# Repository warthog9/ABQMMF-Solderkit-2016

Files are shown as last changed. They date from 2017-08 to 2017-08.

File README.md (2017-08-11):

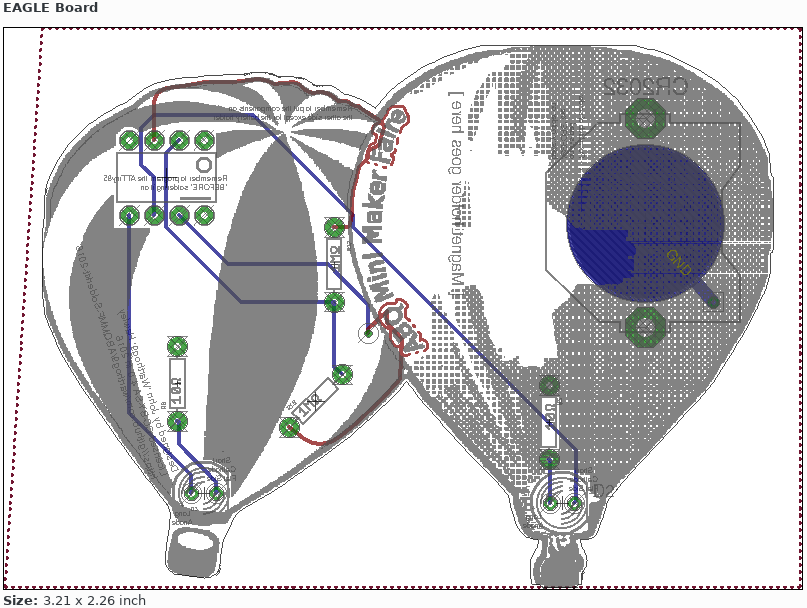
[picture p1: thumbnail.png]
Thumbnail of balloon soldering kit

This is the learn to solder badge for the Albuquerque Mini Maker Faire.

License:
	The design is opened based on the Creative Commons CC-BY-SA 4.0
	[https://creativecommons.org/licenses/by-sa/4.0/](https://creativecommons.org/licenses/by-sa/4.0/)

	Copyright on the badge is held by John 'Warthog9' Hawley

	The badges themselves use a silkscreen that has elements that
	have been removed from this repository, they are not required
	for the functionality, and were removed out of respect for the
	various originators of the symbols.

	Rough outline of the balloons was adapted from
	[https://pixabay.com/en/hot-air-balloon-balloon-striped-312574/](https://pixabay.com/en/hot-air-balloon-balloon-striped-312574/)
	which was listed as released into Public Domain when acquired on
	May 27, 2016

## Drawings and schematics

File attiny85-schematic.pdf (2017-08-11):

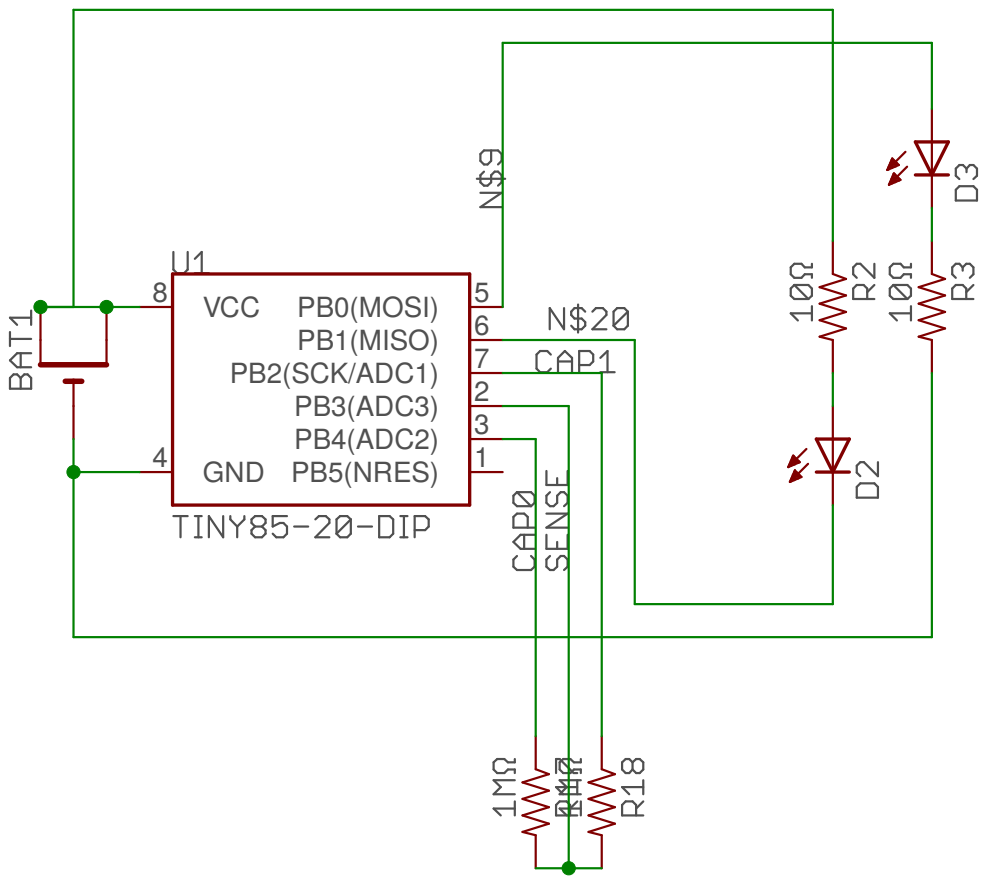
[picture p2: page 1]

8/10/17 7:42 PM /home/warthog9/eagle/ABQ Maker Faire Soldering Kit/attiny85.sch (Sheet: 1/1)

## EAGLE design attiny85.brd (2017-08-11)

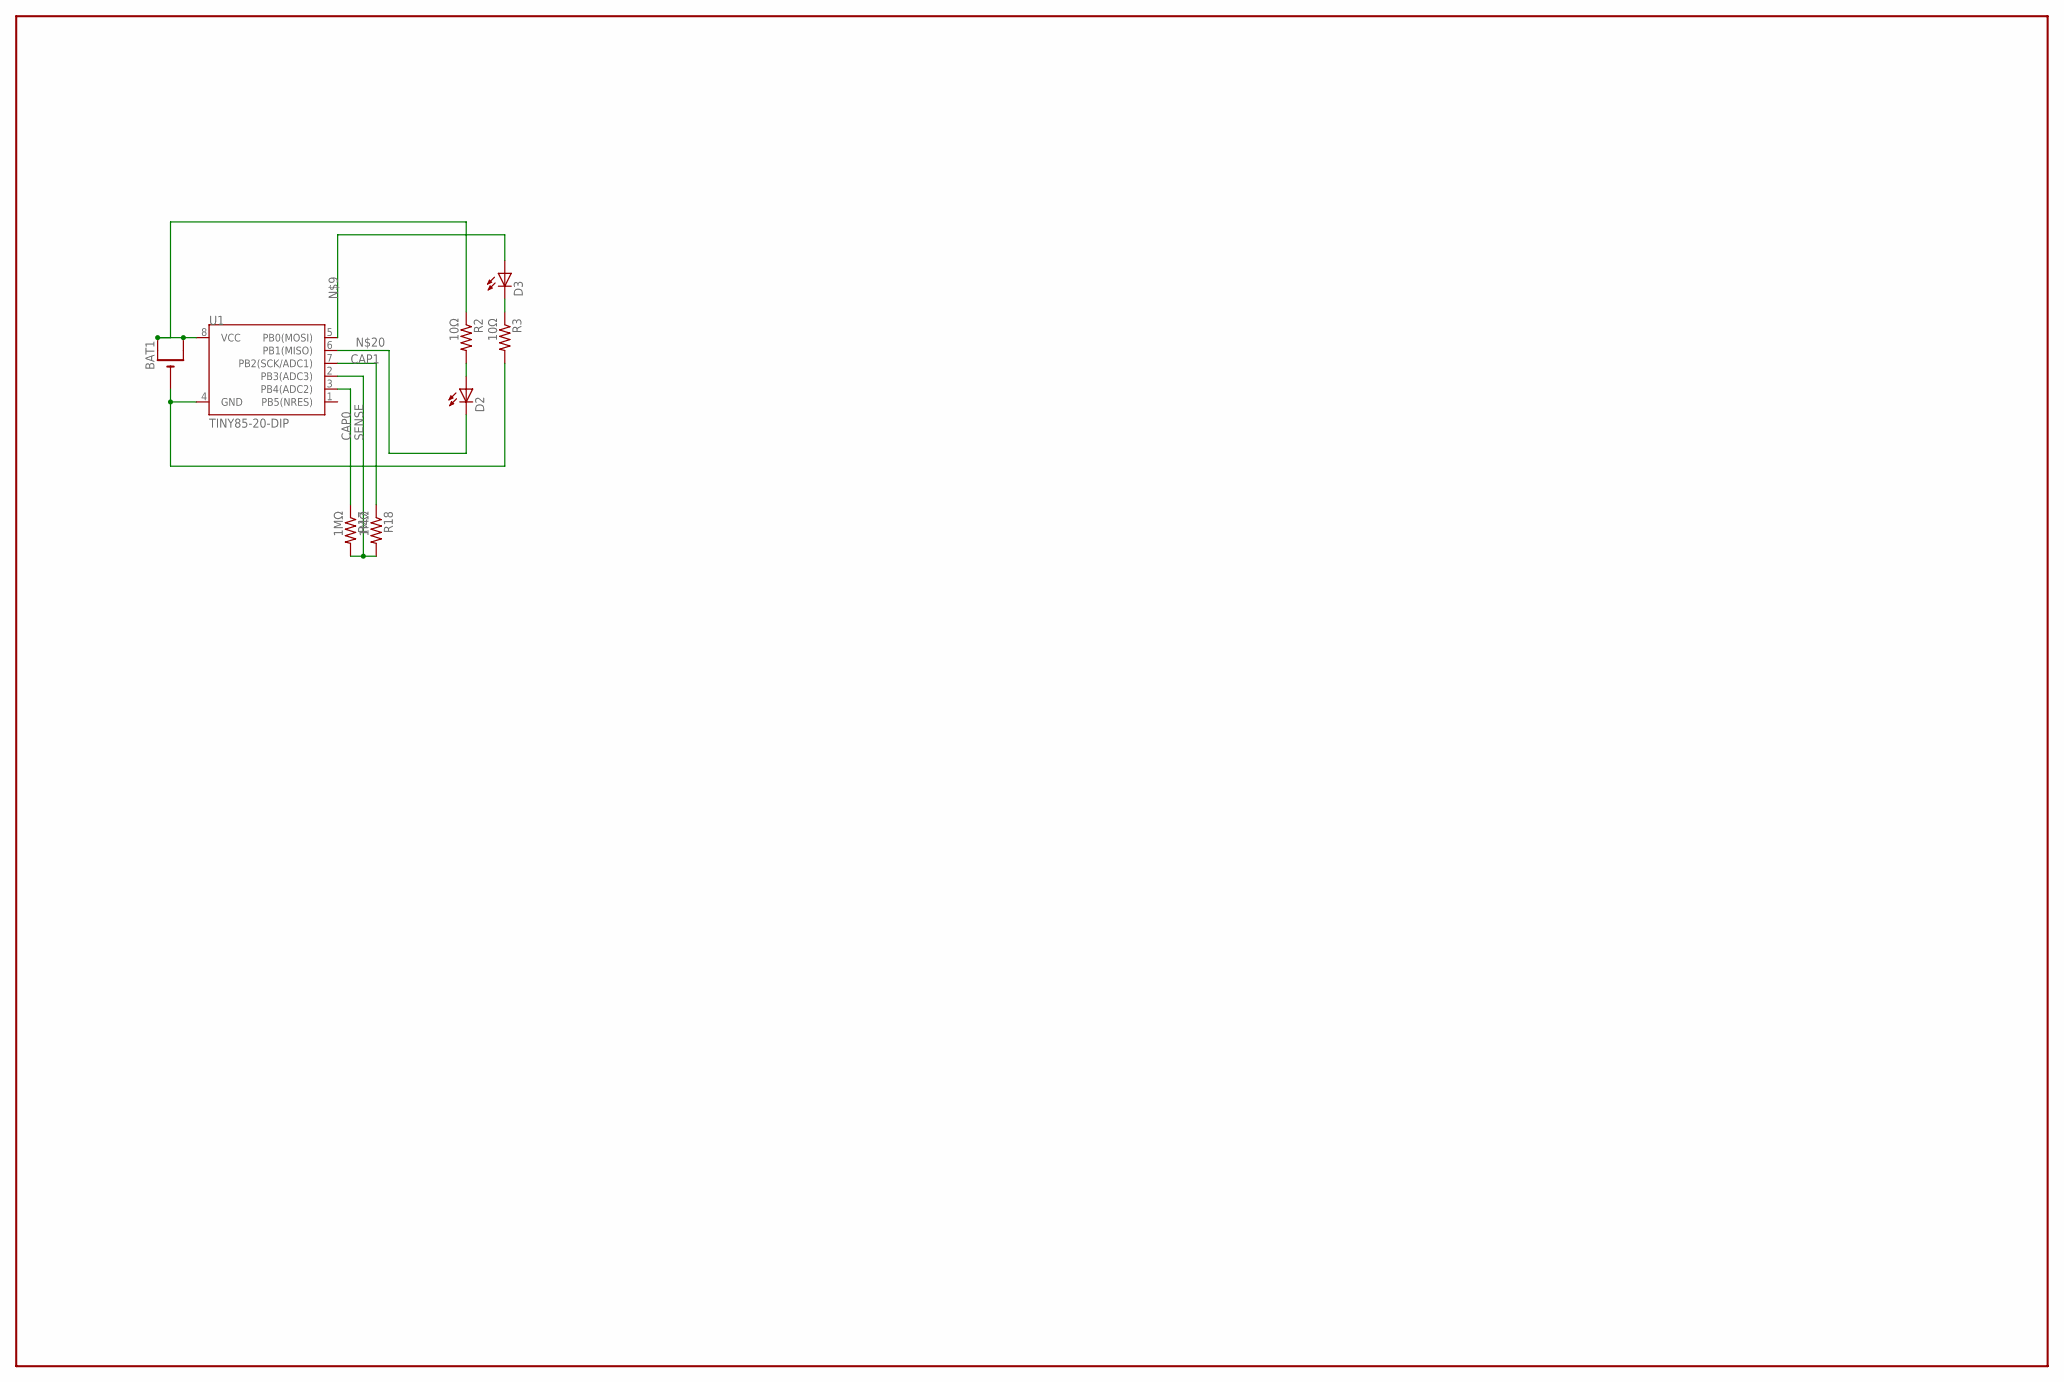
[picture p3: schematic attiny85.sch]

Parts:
BAT1: CR2032THM; CR2032-THRU
D2, D3: LED5MM
R2, R3: 10Ω; AXIAL-0.3
R17, R18: 1MΩ; AXIAL-0.3
U1: TINY85-20-DIP; DIP08

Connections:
CAP0: R17.P$1 (1), U1.3 (PB4(ADC2))
CAP1: R18.P$1 (1), U1.7 (PB2(SCK/ADC1))
GND: BAT1.-, R3.P$2 (2), U1.4 (GND)
unnamed: D2.A, R2.P$2 (2)
unnamed: D3.K (C), R3.P$1 (1)
unnamed: D3.A, U1.5 (PB0(MOSI))
unnamed: D2.K (C), U1.6 (PB1(MISO))
SENSE: R17.P$2 (2), R18.P$2 (2), U1.2 (PB3(ADC3))
VCC: BAT1.+1 (+), BAT1.+2 (+1), R2.P$1 (1), U1.8 (VCC)

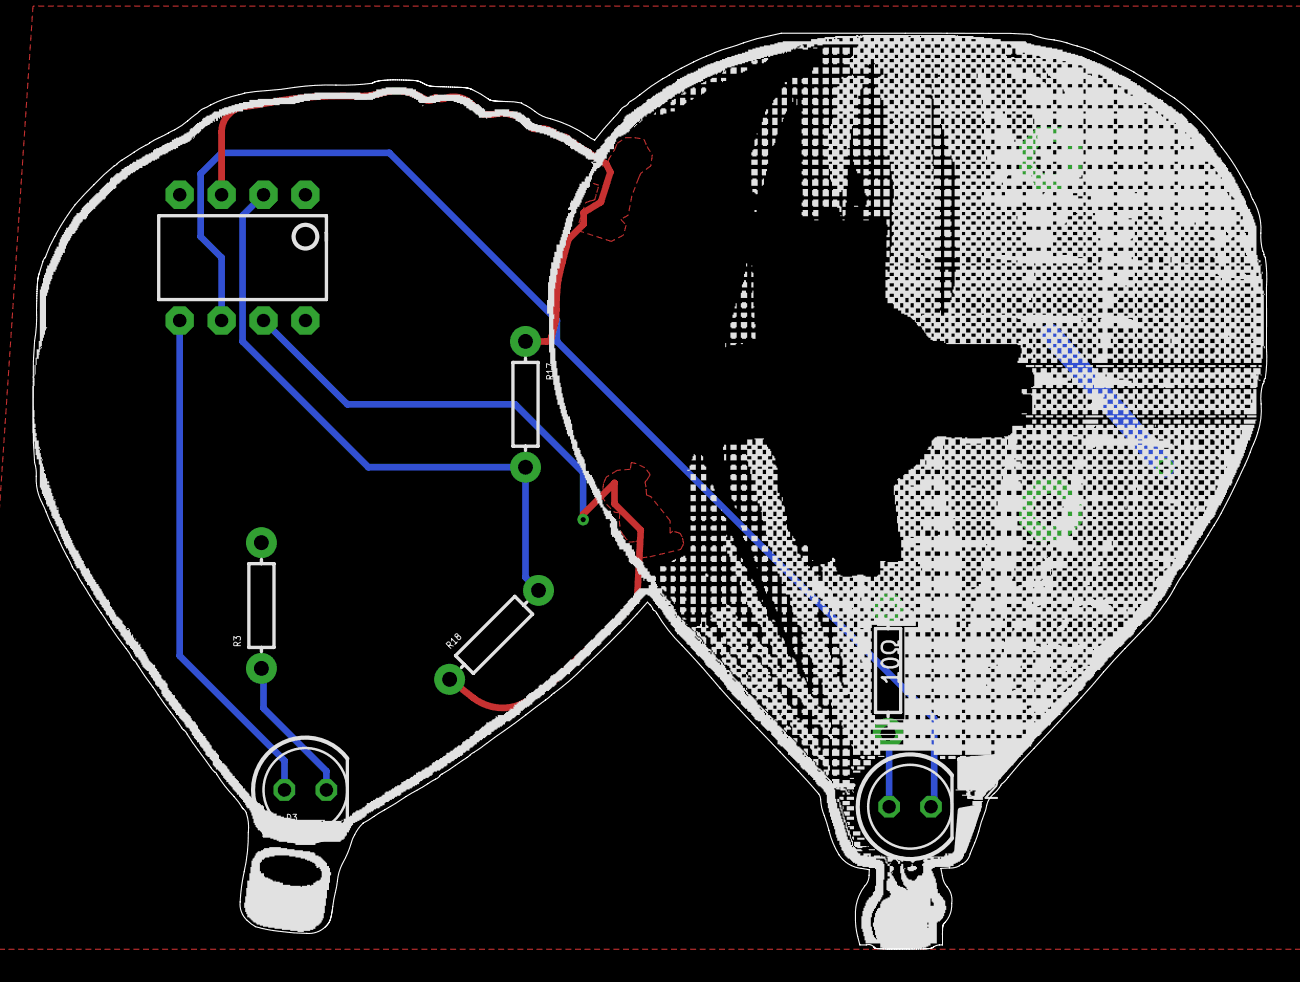
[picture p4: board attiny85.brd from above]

Board: 2 copper layers, 74.7 x 55.5 mm, 8 parts (1 on the bottom side), 9 nets.

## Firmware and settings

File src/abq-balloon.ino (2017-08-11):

int leftBaloonLEDPin = 0;
int rightBaloonLEDPin = 1;

int abqTouchPin = 2;
int faireTouchPin = 4;

int maxBrightness = 128;

void setup()
{
  pinMode(leftBaloonLEDPin, OUTPUT);
  pinMode(rightBaloonLEDPin, OUTPUT);
  
  digitalWrite(leftBaloonLEDPin, HIGH);   // sets the LED on
  delay(1000);                  // waits for a second
  digitalWrite(leftBaloonLEDPin, LOW);    // sets the LED off
  delay(1000);                  // waits for a second
  
  digitalWrite(rightBaloonLEDPin, LOW);   // sets the LED on
  delay(1000);                  // waits for a second
  digitalWrite(rightBaloonLEDPin, HIGH);    // sets the LED off
  delay(1000);                  // waits for a second
  
  // Left pin low is off
  digitalWrite(leftBaloonLEDPin, LOW);
  // right pin, high should be off
  digitalWrite(rightBaloonLEDPin, HIGH);
}

void loop()
{
  int state = random(0,2);
  
  if( state == 0 || state == 1){
    
    // Run one LED
    
    int whichLED = 0;
    
    if( state == 0 ){
       // Run the left LED
       whichLED = leftBaloonLEDPin;
    } else if( state == 1 ){
      // Run the right LED
      whichLED = rightBaloonLEDPin;
    }

    // fade the LED on thisPin from off to brightest:
    for (int brightness = 0; brightness < maxBrightness; brightness++) {
      int useBright = brightness;
      if( state == 1 ){
        // right led
        useBright = 255 - brightness;
      }
      analogWrite(whichLED, useBright);
      delay(5);
    }
  
    // Flicker at the "top" of the brightness, like a balloon
    int totalHighTime = random(250,1500);
  
    for (int highTime = 0; highTime <= totalHighTime; highTime = highTime + 5) {
      int randBright = random(maxBrightness - 50,maxBrightness);
      int useBright = randBright;
      
      if( state == 1 ){
        // right led
        useBright = 255 - randBright;
      }
      
      analogWrite(whichLED, useBright);
      delay(5);
    }
    // end "top" flicker
  
    // fade the LED on thisPin from brithstest to off:
    for (int brightness = maxBrightness; brightness >= 0; brightness--) {
      int useBright = brightness;
      
      if( state == 1 ){
        // right led
        useBright = 255 - brightness;
      }
      
      analogWrite(whichLED, useBright);
      delay(2);
    }
  
    int totalLowTime = random(250,1500);
  
    for (int lowTime = 0; lowTime <= totalLowTime; lowTime = lowTime + 5) {
      int useBright = random(0,12);
      
      if( state == 1 ){
        // right led
        useBright = 255 - useBright;
      }
      analogWrite(whichLED, useBright);
      delay(5);
    }
    
    if( state == 0 ){
      analogWrite(whichLED, 0);
    } else if( state == 1 ){
      analogWrite(whichLED, 255);
    }
  
    // Pulse
    if( random() % 2 == 0 ){
      for (int brightness = 0; brightness < maxBrightness; brightness++) {
         int useBright = brightness;
      
         if( state == 1 ){
           // right led
           useBright = 255 - brightness;
         }        
         
         analogWrite(whichLED, useBright);
         delay(5);
      }
      for(int x = 0; x < random(1,5); x++){
        for (int brightness = maxBrightness; brightness >= 0; brightness--) {
          int useBright = brightness;
      
          if( state == 1 ){
            // right led
            useBright = 255 - brightness;
          }        
         
          analogWrite(whichLED, useBright);
          delay(5);
        }      
      }
    }
  } else if( state == 2 ){
    // Run both LEDs
  } // end if statement
  
  delay(random(2500,15000));
}

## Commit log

2017-08-11 Minor Cleanups - Silkscreen & Battery Holder
    Battery Holder: Updated so that the rest of the plane isn't also
    exposed on the board
    Silkscreen: mostly minor adjustments, and exposing the right led
    resistor
    [attiny85.brd, attiny85.sch]
2017-08-11 Updating resistor values
    [attiny85.brd, attiny85.sch]
2017-08-11 Mucking with spacing around the resistor
    [attiny85.brd]
2017-08-11 More fixing of values
    [attiny85.brd, attiny85.sch]
2017-08-11 Adjusting a routing issue
    [attiny85.brd]
2017-08-11 Updating some wording to fit on board after CAM
    [attiny85.brd]
2017-08-11 Adding Gerbers
    [attiny85.drills.xln]
2017-08-11 Adding Arduino Source Code + hex output
    This requires that you have the Arduino board information from
    https://github.com/damellis/attiny
    which is more easily consumed from Sparkfun's site here:
    https://cdn.sparkfun.com/assets/learn_tutorials/1/5/0/attiny-ide-1.6.x.zip
    an entire tutorial on how to set this up can be found here:
    https://learn.sparkfun.com/tutorials/tiny-avr-programmer-hookup-guide
    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
2017-08-11 Adding schematic for the project

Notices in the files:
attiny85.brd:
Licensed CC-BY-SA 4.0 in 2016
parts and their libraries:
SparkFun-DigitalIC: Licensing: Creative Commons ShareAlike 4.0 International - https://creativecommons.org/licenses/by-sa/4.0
